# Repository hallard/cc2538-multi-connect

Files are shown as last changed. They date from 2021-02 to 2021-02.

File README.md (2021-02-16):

Zigbee CC2538 + CC2592 Multi Connect Board
==========================================

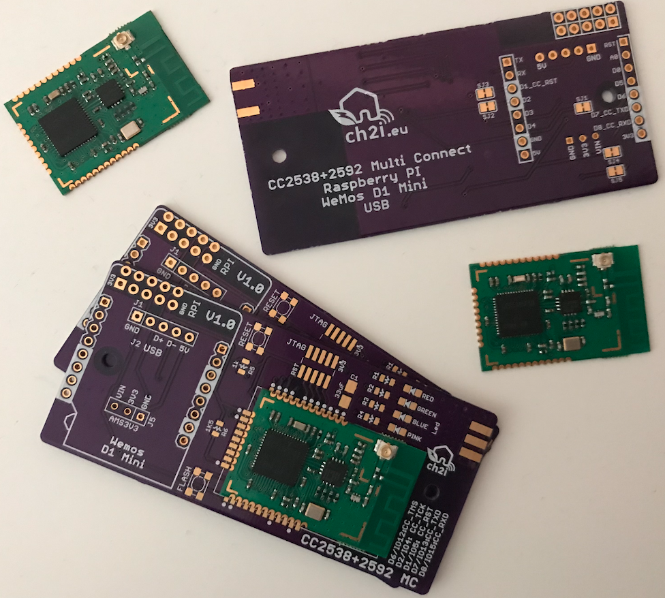
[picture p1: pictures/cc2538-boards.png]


This is just a quick and dirty PCB breakout board, it could be done better, but the fact is that is does the jobs and it does well. It has been designed with free version of Eagle Cad PCB (V7.7).

The first idea and project was made by @jonoxer with this Z2T aka Zigbee2Tasmota board. You can find original project [here](https://github.com/SuperHouse/Z2T). I won't take any credit on what already done, just used his work (thanks to open source) added new ZigBee chip and some features like:

- Easy to build and solder, 0805 CMS components, the trickiest is the CC2538 module
- just but what you need, not all components are needed (but ZigBee chip CC2538 at least)
- Can works in USB mode, connect to any equiped with USB port CPU (Computer, raspberry, router, ...)
- Can be pluged in Serial mode directly on Raspberry PI
- Can be pluged in Serial mode to any equiped with USB port CPU using FTDI like USB Serial adapturs
- Can be used in standalone mode by adding ESP8266 Wemos Mini D1 board with Tasmota Firmware
- Wired 4 Leds, and 3 are controlled by Z-Stack 3 firmware
- 2 push buttons for Reset / Boot mode (to be able to flash Z-Stack firmware on CC2538)
- JTAG connector (never used)
- SMA footpring for those needed 
- fit on classic Aliexpress cheap enclosures

Detailed Description
====================

This repo is not intented to be a reference for ZigBee stuff and how this ZigBee PCB is working. It's for makers who know what they do with DIY electronic boaards and associated software. Anyway everyone could do and use this board with further reading and some patience.

So there is no specific documentation, but you'll find below some references to start of course, please read carrefelly the following links before opening any issue.

- Starting point [discussion](https://github.com/Koenkk/zigbee2mqtt/discussions/1568) about this module on @Koenkk github
- Tasmota [ZigBee documentation](https://tasmota.github.io/docs/CC2530/)
- @jethome-ru Z-Stack [Firmware](https://github.com/jethome-ru/zigbee-firmware/tree/master/ti/coordinator/cc2538_cc2592) used and instruction to flash

To be honest, the easiest way I found to flash firmware is to use one FTDI USB Serial adapter (take care one with 3.3V regulator, not 5V) and [cc2538prog](https://github.com/1248/cc2538-prog) using WeMos Mini D1 header

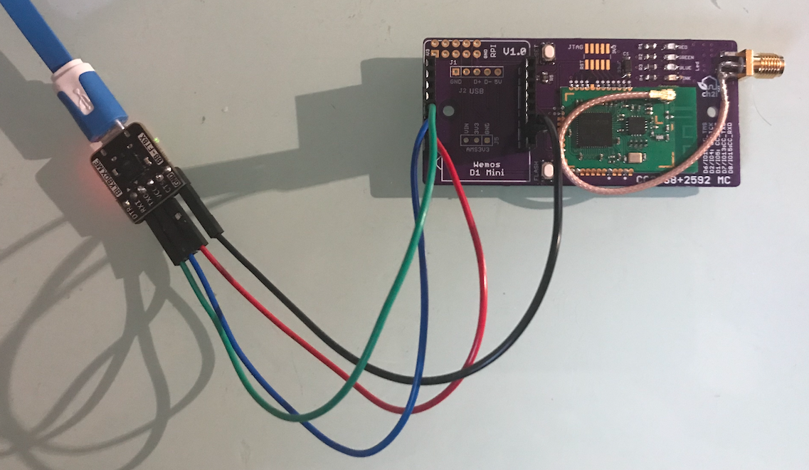
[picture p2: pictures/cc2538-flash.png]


Installation
============

Depending on final use you want and I won't describe all here since there is a huge mix of possibilities, I consider after reading, tpi know how and with what you want to use this board.

## Hardware 

- Standalone with WeMos Mini D1
- on Raspberry PI Serial
- on USB computer
- ...

## Sofware

- Tasmota
- ZigBee2Mqtt
- Zigpy
- ...

Schematics
==========

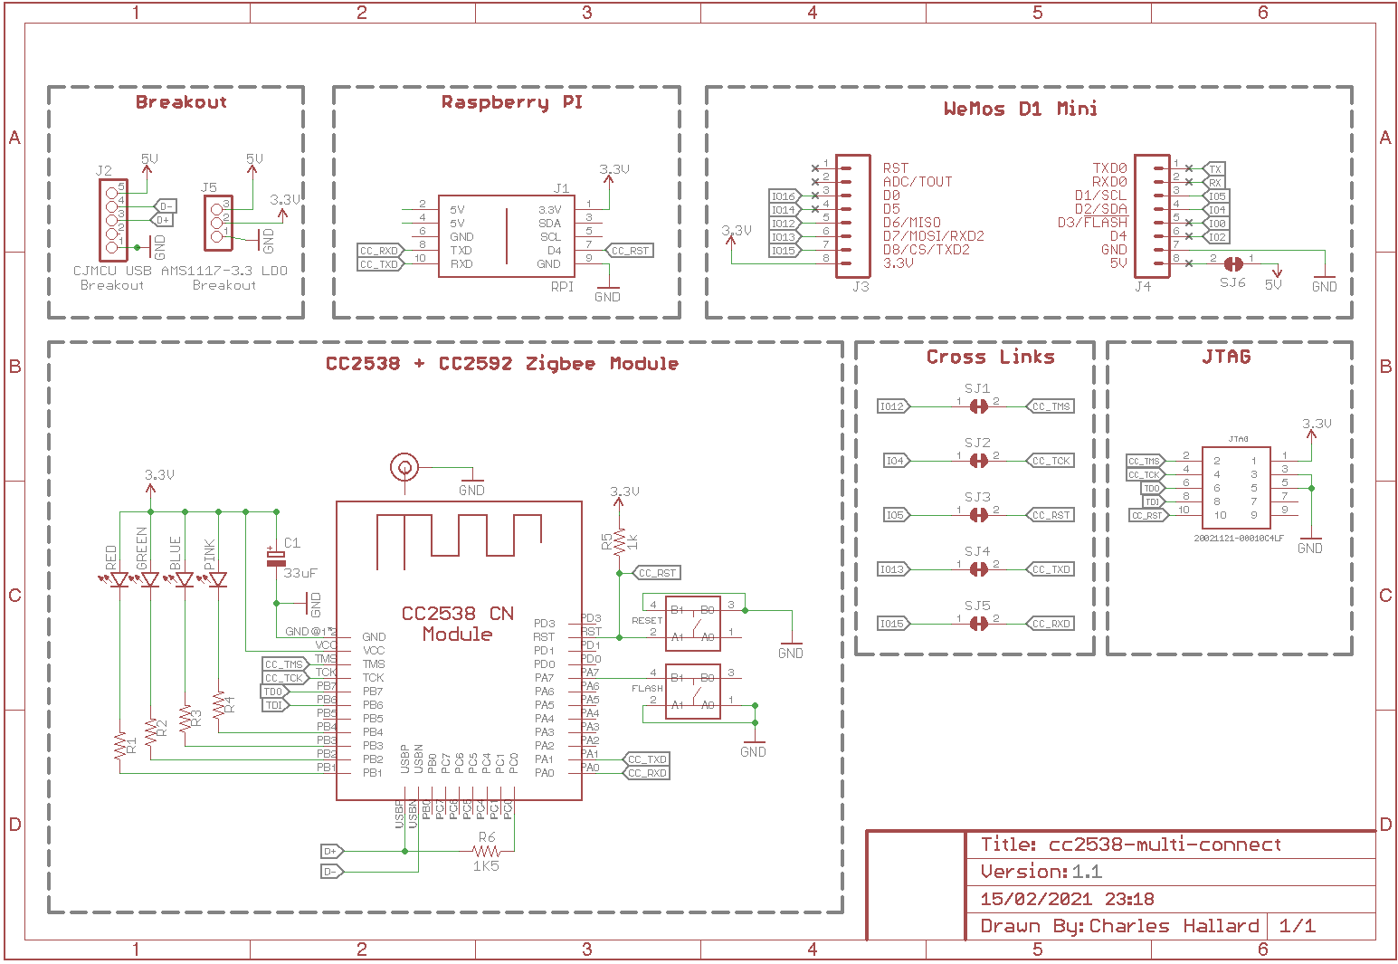
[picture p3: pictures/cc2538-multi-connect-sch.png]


Bill Of Material (BOM)
======================

Nothing fancy, all components are 0805 and/or PTH and can be ordered almost anywhere (digikey, mouser, radiospare, ...). 
use only what you need dependings on what you want to do. 

- This board [PCB](https://oshpark.com/shared_projects/3h5YvEEm) of course 
- cc2538 module take care check the footprint there are differents vendors with different footprints
- R5 any 1K 0805 SMD
- R6 any 1K5 0805 SMD
- C1 33uF (or plus) 1206 tantale capacitor (used one of my boxes, don't know ref)
- 2 x Tactile switch such as SKRPACE010 (4.2x3.2x2.5mm)
- If you want LEDs, 4 SMD 0805 Led plus associated resistor
  - R1 Red = 1K 0805 (Power)
  - R2 Green = 1K 0805 (not used by firmware yet)
  - R3 Blue R3 = 330 ohm 0805 (join mode)
  - R4 Pink or other = 330 Ohm 0805 (ZigBee communication)
- If wanted, PI Connector `2.54 mm 2x5 pin Female Double Row`
- If needed USB Breakout `micro USB to DIP adapter Converter 2,54 mm PCB Breakout`
- If needed 3.3V Regulator `DC 5V to 3.3V Step-Down Power Supply Module AMS1117-3.3` (if powered thru USB without WeMos for Example)
- If needed enclosure `Waterproof Plastic Clear Cover Enclosure Case 85*58*33MM`
- Loved this USB/Serial 3.3V [module](https://aliexpress.com/item/32664922086.html), very cheap and do all job but looks hard to find now, but still available on some places.

Text noted in `between like this one` means type text in google to find seller (Aliexpress, Ebay, ...)

Assembling Boards 
=================



[PCBs.io](https://www.pcbs.io/) was giveing me some reward when ordering my designed boards from their site. This was pretty good, because I useed these rewards to create and design new boards and order boards for a discounted price, but looks like PCBs.io is gone, I do not have any rewards from PCBs.io since August 2020 and my free order placed after are still not received, so my guess they are not on business anymore.

So you can order the board on [oshpark](https://oshpark.com). 

- [V1.0](https://oshpark.com/shared_projects/3h5YvEEm) 

It's a pitty after several discuss with OSHPark that I can't have any rewards for each people ordering my boards, this would allow me to order free PCB for shared projects and create new ones. For information my shared boards generated a total of **$285 162.00** orders at PCBs.io in 4 years, not bad at all :-)

Hoping one day OSHparks will thanks me giving them this market. 

As soldering CC2538 can be tricky, you can just solder needed pin marked with white dot on each. If not using JTAG or LED you can even solder less, check schematics.

Example of Assembled boards 
===========================

**Standalone With WeMos Mini D1**
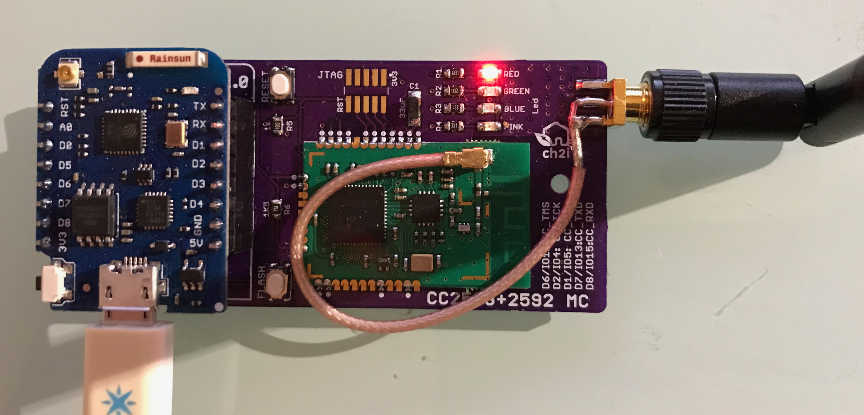
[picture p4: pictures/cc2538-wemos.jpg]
Fully assembled with WeMos Mini D1


**In USB Mode (with USB firmware)**
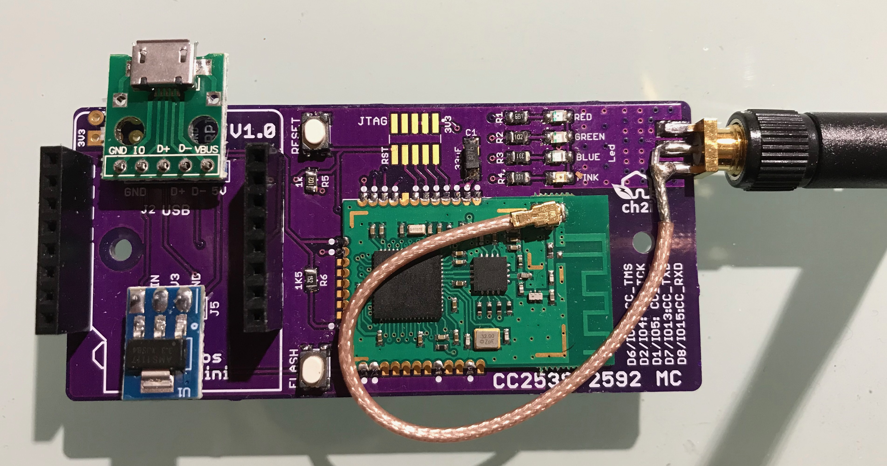
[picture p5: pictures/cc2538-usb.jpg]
Fully assembled, standalone mode


**Packaged into enclosure**
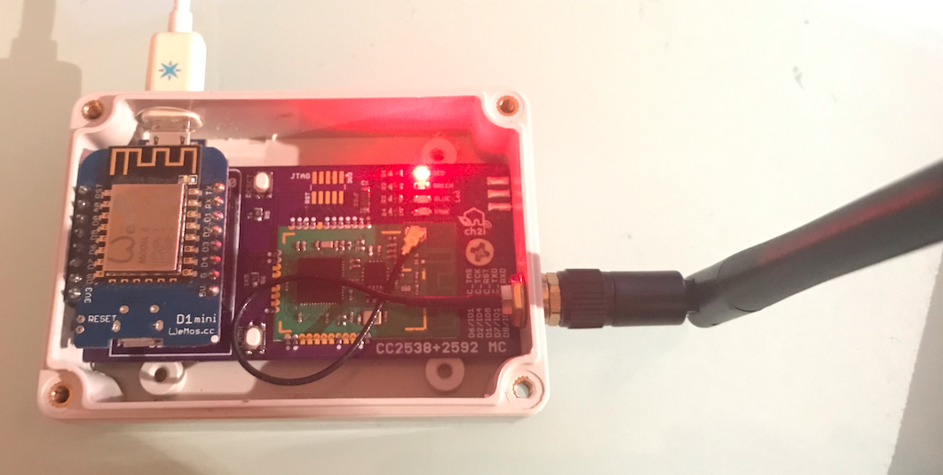
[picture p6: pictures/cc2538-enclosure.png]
With enclosure


License
=======

I kept the original one so

Copyright 2020 SuperHouse Automation Pty Ltd www.superhouse.tv

The hardware portion of this project is licensed under the TAPR Open Hardware License (www.tapr.org/OHL). The "license" folder within this repository contains a copy of this license in plain text format.

The software portion of this project is licensed under the Simplified BSD License. The "licence" folder within this project contains a copy of this license in plain text format.

Misc
====

See news and other projects on my [blog][1] 
 
[1]: https://hallard.me

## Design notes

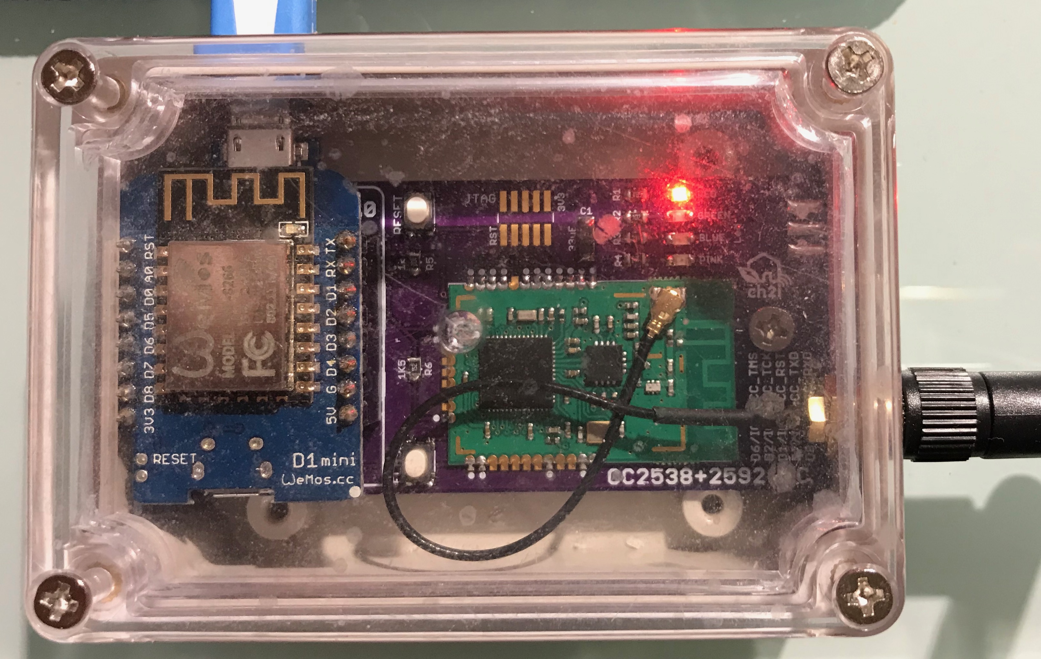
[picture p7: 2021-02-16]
pictures/cc2538-enclosure.jpg

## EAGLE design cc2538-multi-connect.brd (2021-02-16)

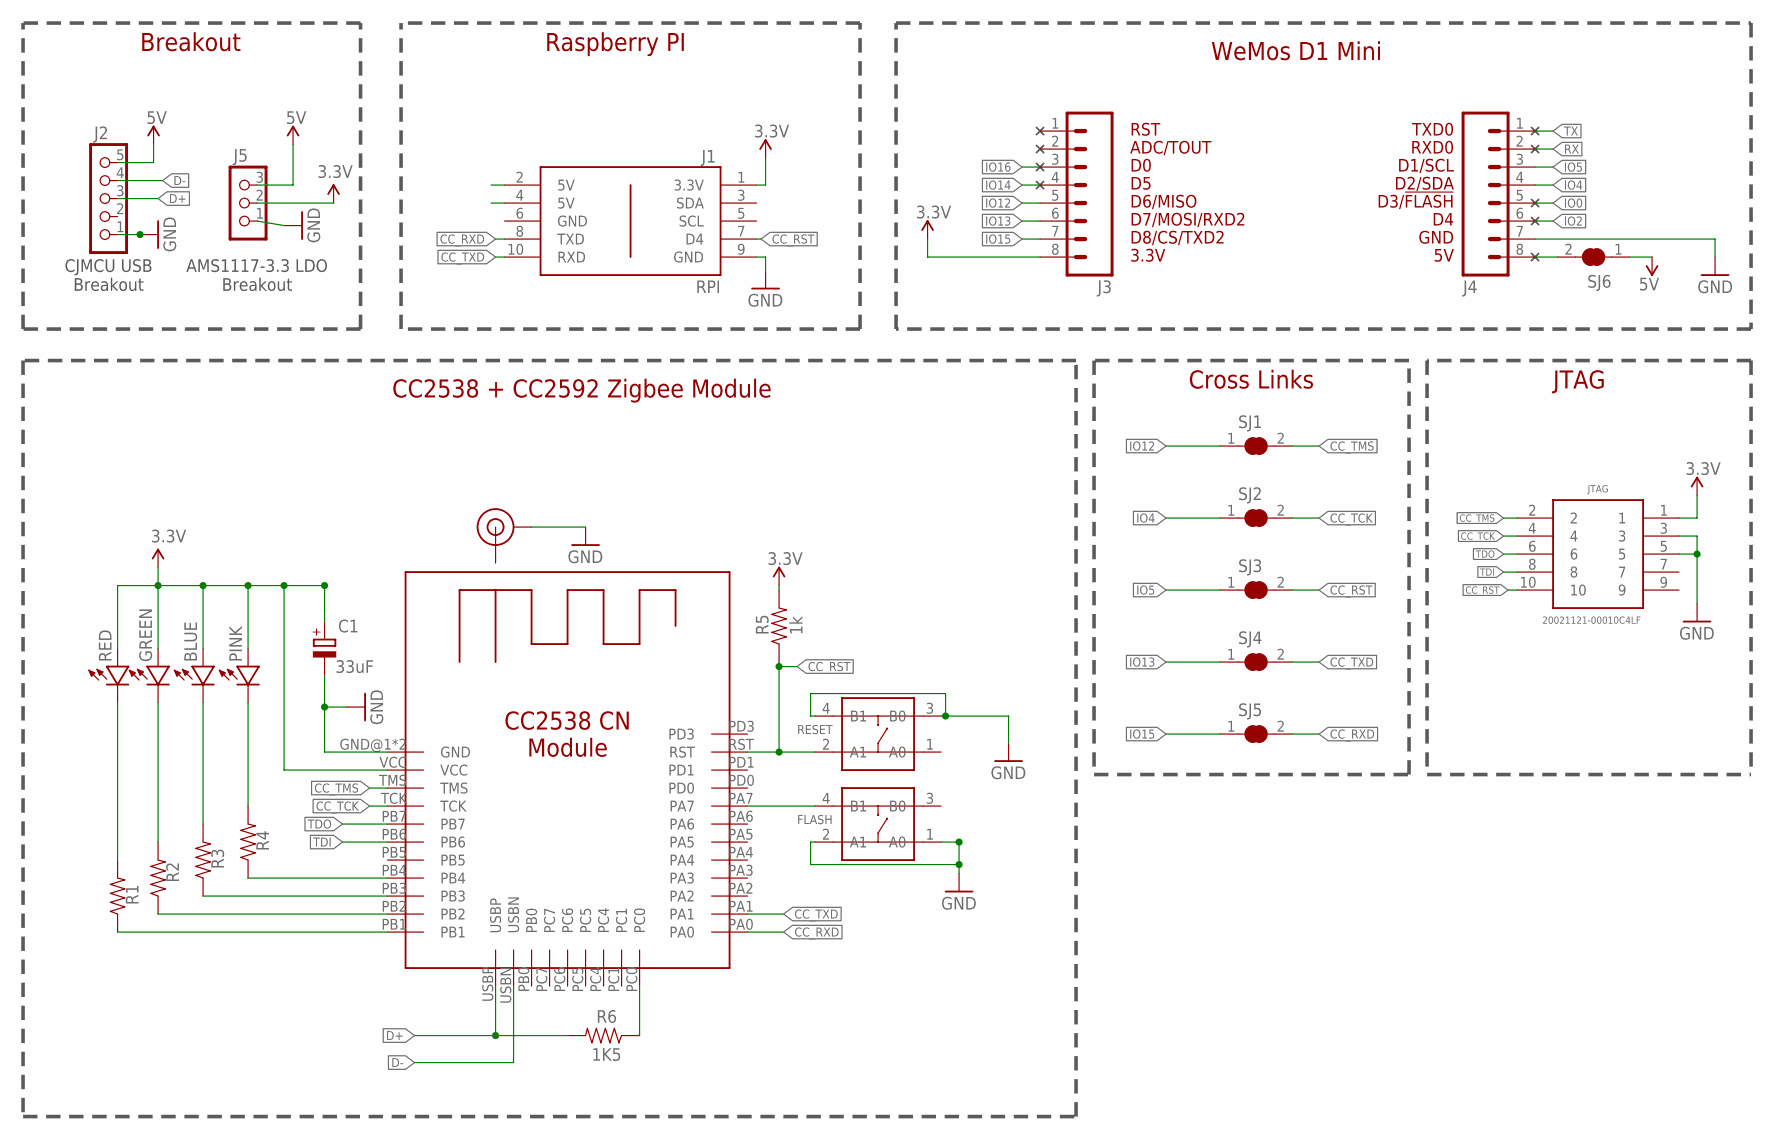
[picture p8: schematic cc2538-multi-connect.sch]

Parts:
BLUE: Led; 0805-LED-LARGEPADS
C1: 33uF; A/3216-18W
FLASH: BOOT; SW4-SMD-4.2X3.2X2.5MM
GREEN: Led; 0805-LED-LARGEPADS
J1: RPI; 2X05
J2: CON_HEADER_1X05-PTH; M1X5
J3, J4: M08; 1X08
J5: CON_HEADER_1X03-PTH; M1X3
J$2: ANTENNAEDGE; SMA-EDGE
JTAG: 20021121-00010C4LF; 2002112100010C4LF
PINK: Led; 0805-LED-LARGEPADS
R1, R2, R3, R4: RESISTOR0805-RES; 0805-RES
R5: 1k; 0805-RES
R6: 1K5; 0805-RES
RED: Led; 0805-LED-LARGEPADS
RESET: BOOT; SW4-SMD-4.2X3.2X2.5MM
SJ1, SJ6: D6/P2_1_DD; SJC
SJ2: D2/P2_2_DC; SJC
SJ3: D1/CC_RST; SJC
SJ4: D7/P0_3; SJC
SJ5: D8/P0_2; SJC
U$27: CC2538-CN

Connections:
3.3V: BLUE.PLUS, C1.+, GREEN.PLUS, J1.1 (3.3V), J3.8, J5.2, JTAG.1, PINK.PLUS, R5.2, RED.PLUS, U$27.VCC
5V: J2.5, J5.3, SJ6.1
5V1: J1.2 (5V)
5V2: J1.4 (5V)
5VD1: J4.8, SJ6.2
CC_RST: J1.7 (D4), JTAG.10, R5.1, RESET.2 (A1), SJ3.2, U$27.RST
CC_RXD: J1.8 (TXD), SJ5.2, U$27.PA0
CC_TCK: JTAG.4, SJ2.2, U$27.TCK
CC_TMS: JTAG.2, SJ1.2, U$27.TMS
CC_TXD: J1.10 (RXD), SJ4.2, U$27.PA1
D+: J2.3, R6.2, U$27.USBP
D-: J2.4, U$27.USBN
FLASH: FLASH.4 (B1), U$27.PA7
GND: C1.-, FLASH.1 (A0), FLASH.2 (A1), J1.9 (GND), J2.1, J4.7, J5.1, J$2.GND@1 (GND), J$2.GND@2 (GND), J$2.GND@3 (GND), JTAG.3, JTAG.5, RESET.3 (B0), RESET.4 (B1), U$27.GND@1 (GND), U$27.GND@2 (GND)
IO0: J4.5
IO2: J4.6
IO4: J4.4, SJ2.1
IO5: J4.3, SJ3.1
IO12: J3.5, SJ1.1
IO13: J3.6, SJ4.1
IO14: J3.4
IO15: J3.7, SJ5.1
IO16: J3.3
unnamed: BLUE.MINUS, R3.2
unnamed: R1.1, U$27.PB1
unnamed: R2.1, U$27.PB2
unnamed: R3.1, U$27.PB3
unnamed: R4.1, U$27.PB4
unnamed: PINK.MINUS, R4.2
unnamed: GREEN.MINUS, R2.2
unnamed: R1.2, RED.MINUS
unnamed: R6.1, U$27.PC0
RX: J4.2
TDI: JTAG.8, U$27.PB6
TDO: JTAG.6, U$27.PB7
TX: J4.1

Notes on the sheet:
D3/!FLASH
D6/MISO
D2/SDA
D1/SCL
RXD0
TXD0
D7/MOSI/RXD2
D8/CS/TXD2
ADC/TOUT
GND
3.3V
RST
Cross Links
CC2538 + CC2592 Zigbee Module
WeMos D1 Mini
JTAG
AMS1117-3.3 LDO Breakout
CJMCU USB Breakout
Breakout
Raspberry PI

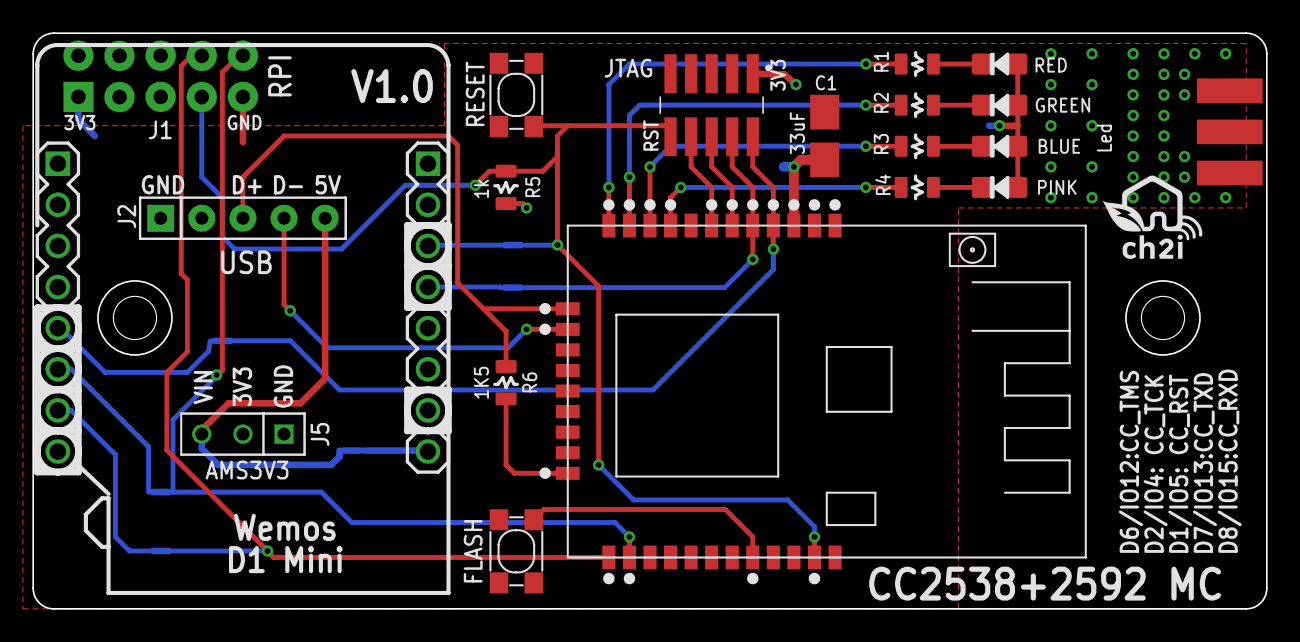
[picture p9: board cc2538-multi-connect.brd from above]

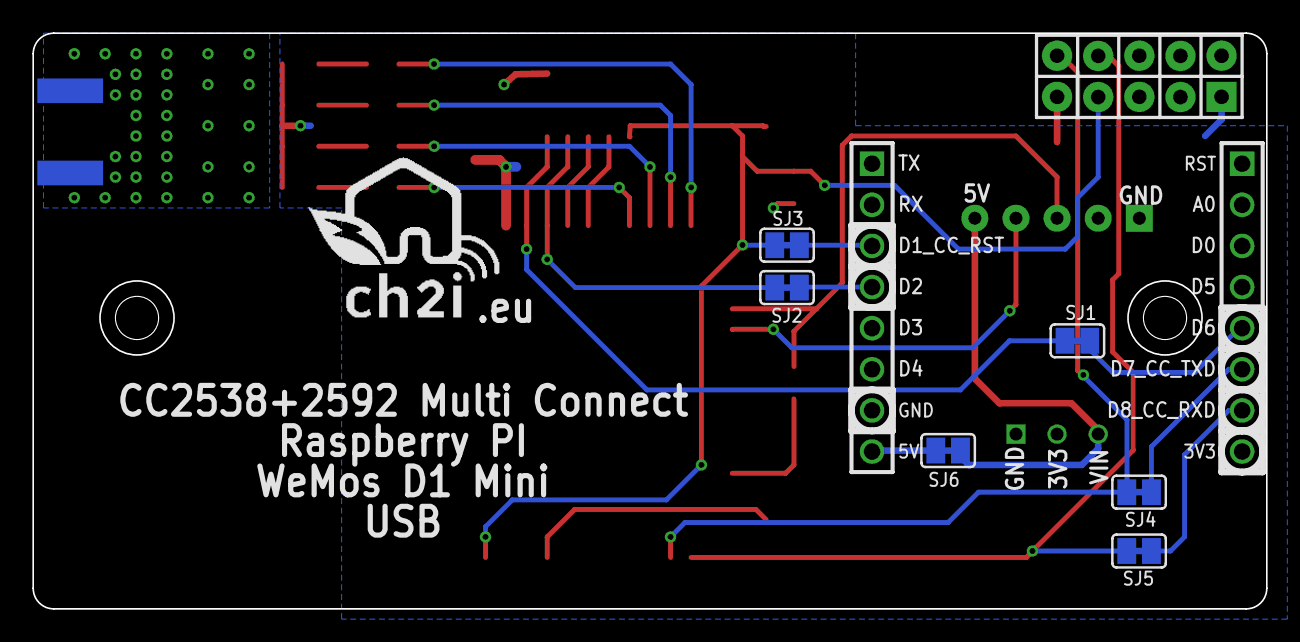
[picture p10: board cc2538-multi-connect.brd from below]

Board: 2 copper layers, 76.2 x 35.6 mm, 29 parts (7 on the bottom side), 28 nets.

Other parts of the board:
U$8: LOGO_C2I_015
U$9: LOGO_CH2I_110MM

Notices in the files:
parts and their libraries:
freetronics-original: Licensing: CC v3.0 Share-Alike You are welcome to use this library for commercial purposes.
